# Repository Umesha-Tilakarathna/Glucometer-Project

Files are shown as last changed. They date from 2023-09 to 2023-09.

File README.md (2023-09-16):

# Glucometer Project
 
The project is a glucometer, that displays the glucose level of the body through
invasive means. When a glucose strip is inserted and a blood drop is placed, the
glucometer processes the reading to display the glucose level in mg/dL. The proportional
current signal generated in the strip is amplified, converted to voltage and processed
using the microcontroller and displayed finally.

The repository contains the Schematic Designs, Altium Designs, Solidwork Designs, 
and the code that was used to process the analog signal. 

gluco

strip

battery

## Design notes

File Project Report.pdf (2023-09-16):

## Department of Electronic & Telecommunication Engineering University of Moratuwa

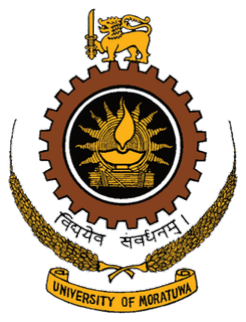
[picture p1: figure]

### EN 2160 - Electronic Design Realization

Final Project Report

### Glucometer

Submitted by:

Tilakarathna. U. A 200664P

## Contents

1 Introduction | 2
2 Product Specifications | 2
3 Functionality | 2
4 Product Architecture | 4
5 PCB Design | 5
6 Enclosure Design | 11
7 Instructions of Assembly | 13
8 Testing for functionality | 13
9 Areas of possible improvement | 13

## Abstract

The project is a glucometer, that displays the glucose level of the body through invasive means. When the glucose strip is inserted and a blood drop is placed, the glucometer processes the reading to display the glucose level in mg/dL. The proportional current signal generated in the strip is amplified, converted to voltage and processed using the microcontroller and displayed finally..

## 1 Introduction

Diabetes is a prevalent and serious disease affecting approximately 400 million people worldwide, and it ranks as the 8th leading cause of death. Managing diabetes is crucial for patients to maintain healthy blood glucose levels and prevent complications. At pharmacies, patients can find a wide variety of blood glucose meters along with their accompanying test strips.

The glucometer functions through the action of a disposable test strip that should be connected into the meter. By performing a finger prick to obtain a small droplet of blood, and loading the blood onto the test strip the blood glucose level is read.

## 2 Product Specifications

After connecting the glucose test strip to the device while the device is switched on, the button on the box should be pressed after placing blood on the strip. Then the glucose level can be observed after 5 seconds that is taken to the reading to achieve steady state. The reading is fed to the atmega328p microcontroller which is connected to an arduino nano board, for processing, and the final output is displayed on a 0.96” OLED display.

The power is supplied by two 2032 3.6V coin cell batteries to ensure the light weight and portability of the device. Three power regulators are used to obtain the required voltages to power the amplifiers, and also for the functionality of the test strip connector.

## 3 Functionality

The device contains a Onetouch Ultra test strip connector to connect the glucose strip to the device. This reading is achieved by amplifying the current generated by the glucose strip, which is proportional to the glucose level of the body by an enzymatic chemical reaction. This current is converted to a voltage by the opamp circuit and is input to the microcontroller as an analog input. Reference voltages of 2.4V and 2.1V is used in the amplification by connecting the voltages to the test strip electrodes through the opamp circuitry.

The reading is generated by the atmega328p microcontroller which is in the arduino nano board connected. The reading should be calibrated before use. For this, an existing glucometer and also a control solution which has a specified glucose level is required. Depending on the values the code should be changed. An OLED display of 0.96” inches is used to display the reading to the user. These are connected to the microcontroller using SDA and SCL pins. Also, the button that resets the reading is also connected to the microcontroller.

Further, an analog switch CD4066BM96 is connected to reset the circuitry.

LM317LCDR is used to generate the 2.1 V. The output voltage of this regulator is adjustable. Therefore, a 1k variable resistor was used for the adjustments. A TPS76925DBVT is used to generate the 2.5V output. To generate the 5V required for the opamps, a 7805 regulator was used.

### 3.1 Functionality of the test strips

There are three electrodes printed into the test strips: a reference electrode, a counter electrode and a working electrode. A fixed voltage is applied and the resulting current after the blood is loaded is monitored. The current response is then related to the glucose concentration through calibration.

Typically the electrodes are coated such that an enzymatic chemical reaction occurs at the electrode surface and this reaction dictates the resulting current. The glucometer developed uses Onetouch Ultra test strips. Here, the current after a fixed time, which is after a short initial transient is used for calibration.

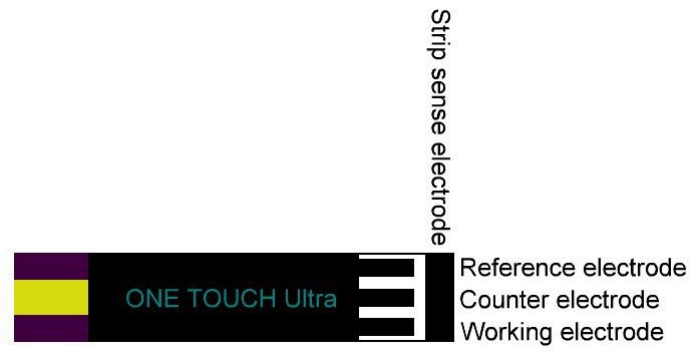
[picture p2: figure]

Figure 1: Onetouch Ultra Test Strip

## 4 Product Architecture

### 4.1 Block Diagram Abstraction of the Device

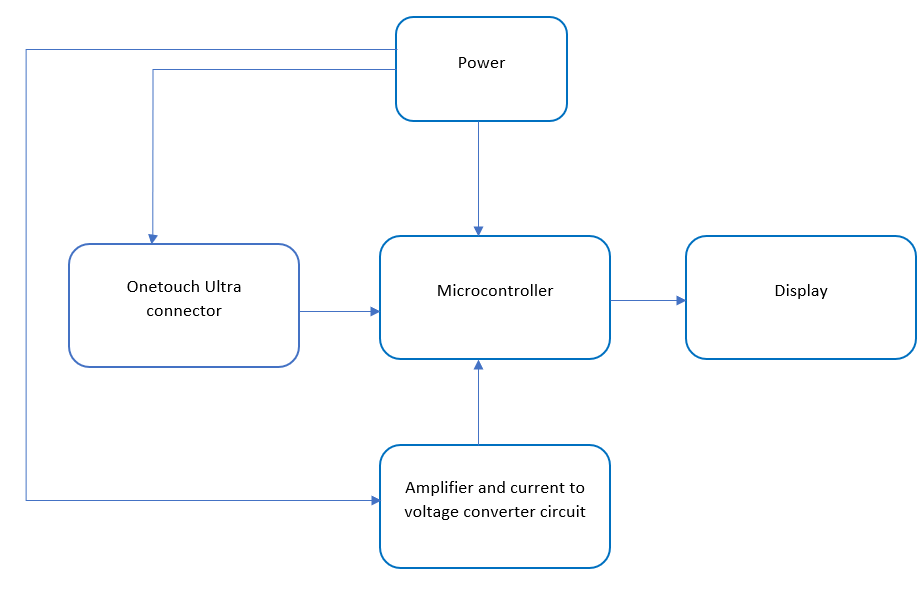
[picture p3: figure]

Figure 2: Block Diagram of the Device

## 5 PCB Design

### 5.1 Schematics

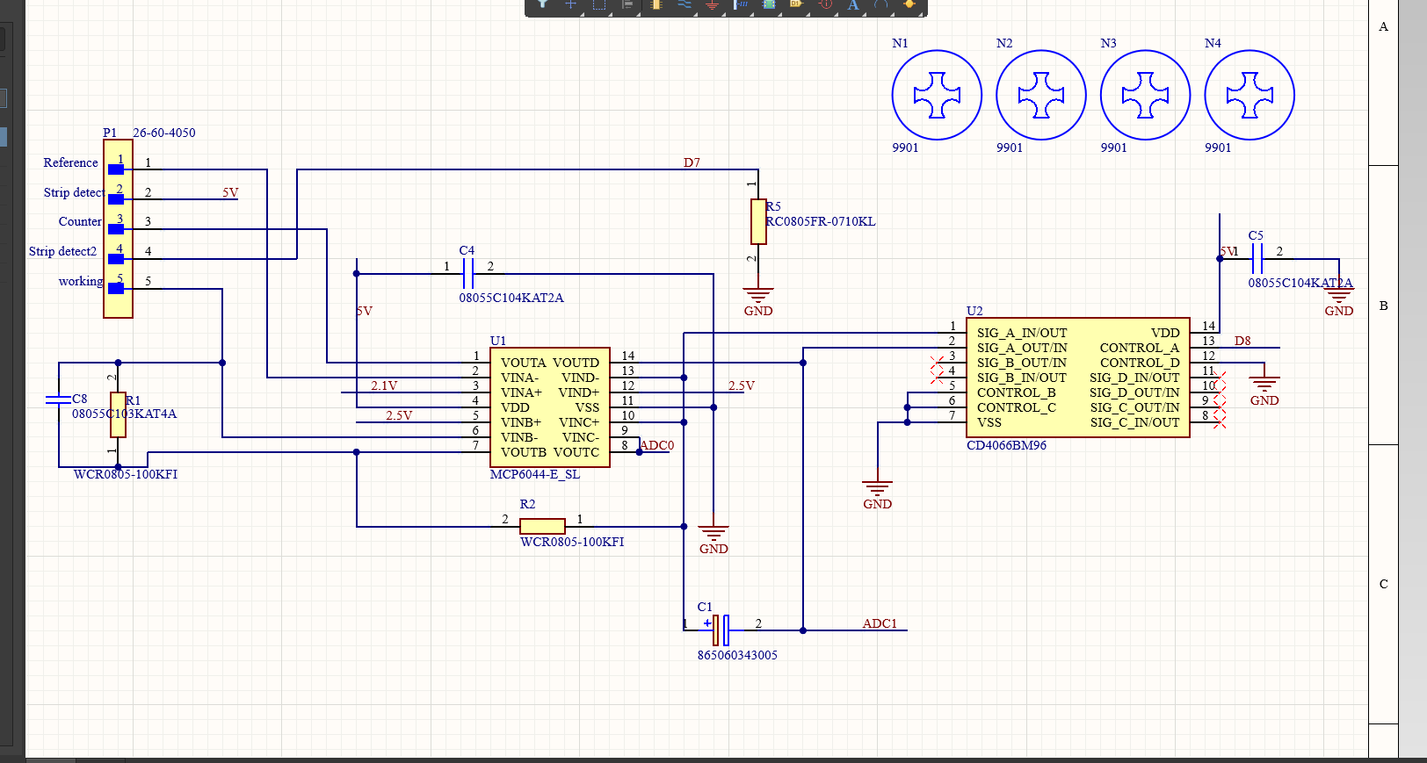
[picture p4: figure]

Figure 3: The Main Circuit

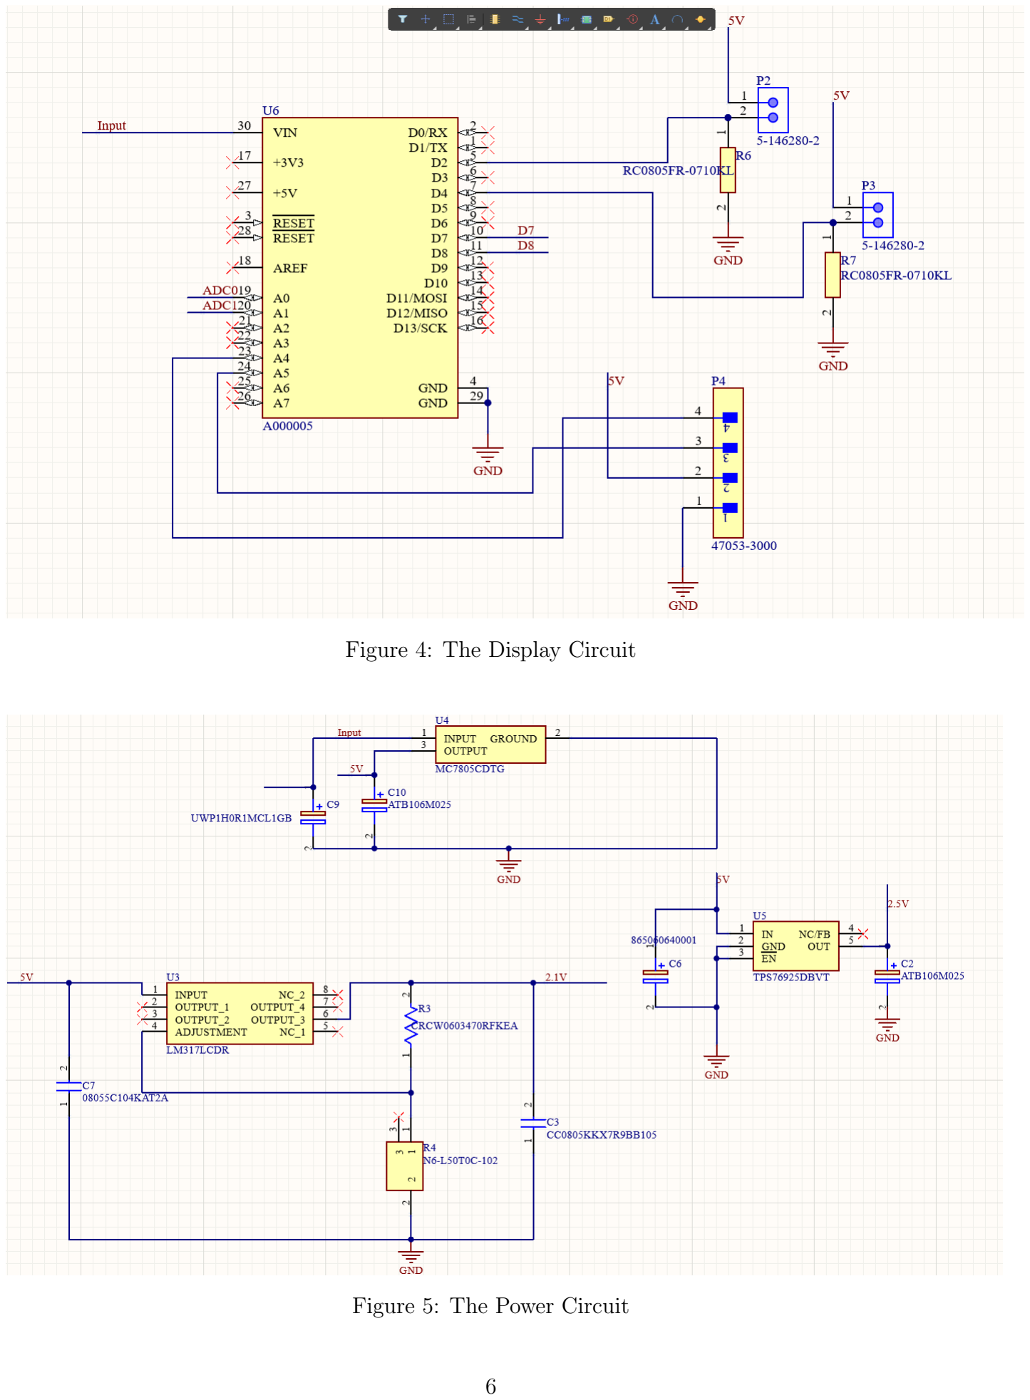
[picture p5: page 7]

Figure 4: The Display Circuit

Figure 5: The Power Circuit

### 5.2 Bill of Materials

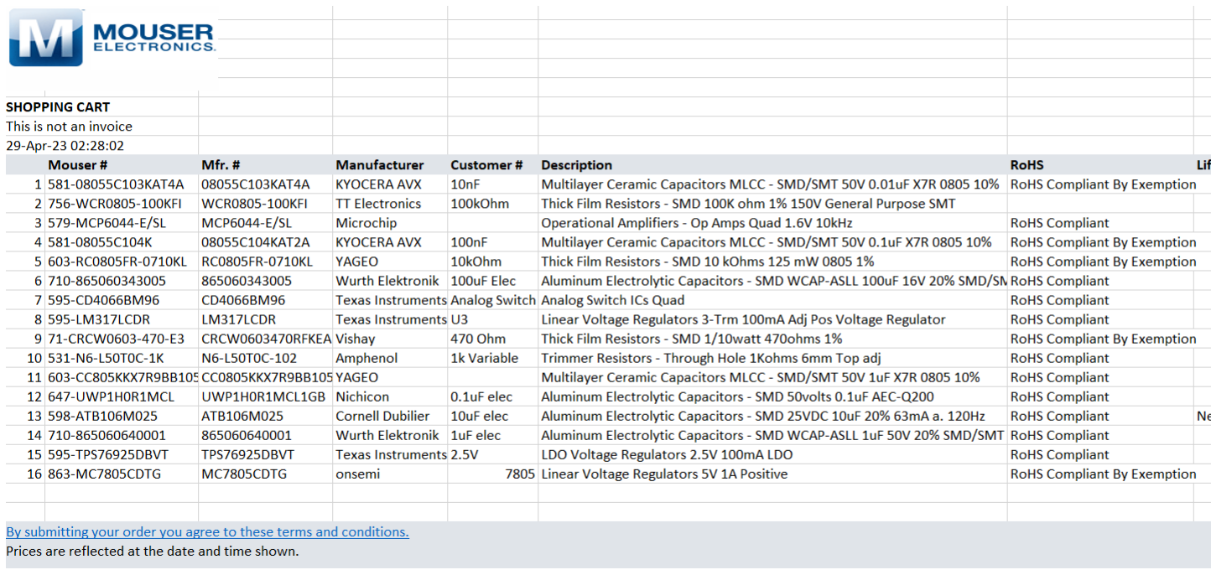
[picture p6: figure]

Figure 6: Bill of Materials of Components

Price of components | Rs. 8450
PCB printing | Rs. 2650
3D printing | Rs. 4000
Other | Rs. 2000
Total prototype production type | Rs. 17,100

### 5.3 PCB Design

The following images are of the PCB design.

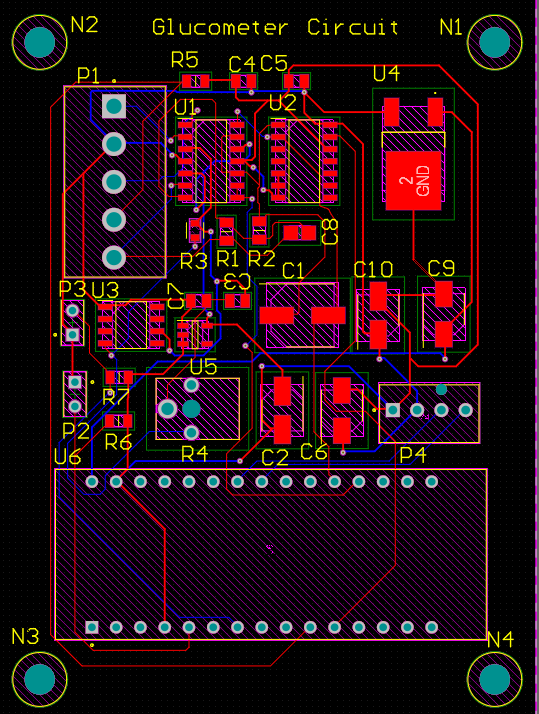
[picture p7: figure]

Figure 7: PCB Design

### 5.4 Programming the microcontroller

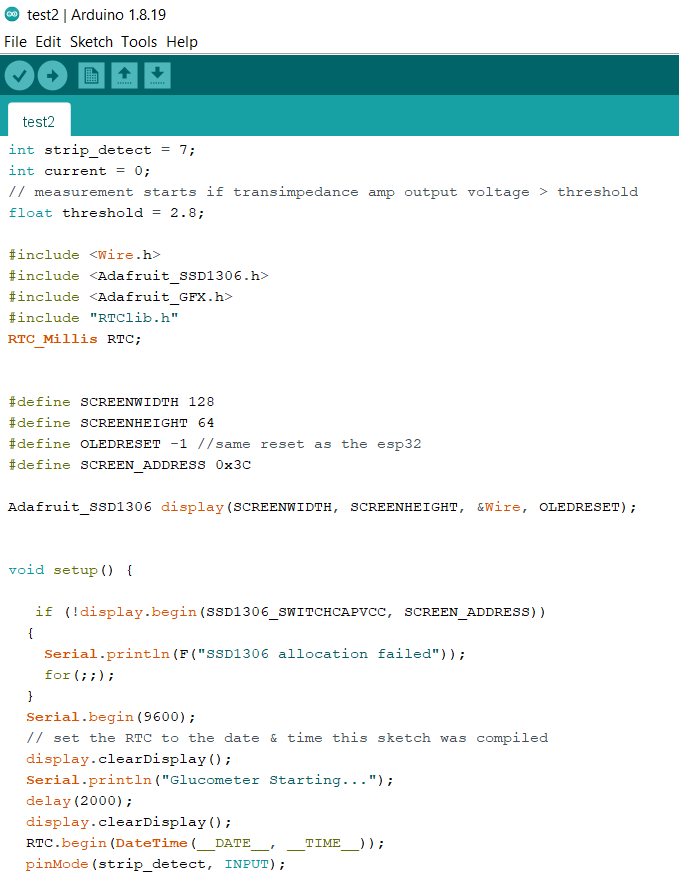
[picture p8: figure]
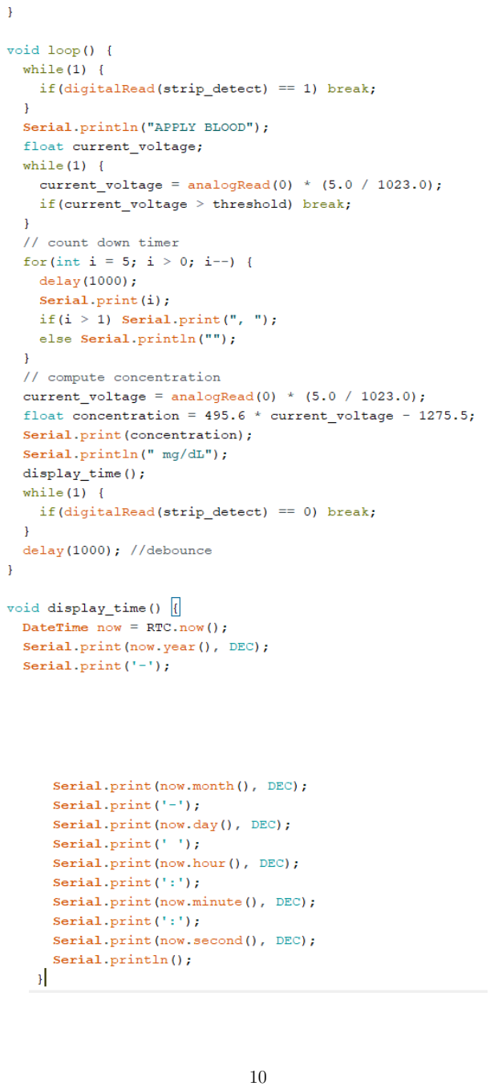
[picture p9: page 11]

## 6 Enclosure Design

The enclosure is made in such a way, that is portable and easy to use with minimal interactions with the device. The top part is connected with the display, and is made in such a way, that is removable for any repairs of the device. Also, the battery compartment can be open when needed.

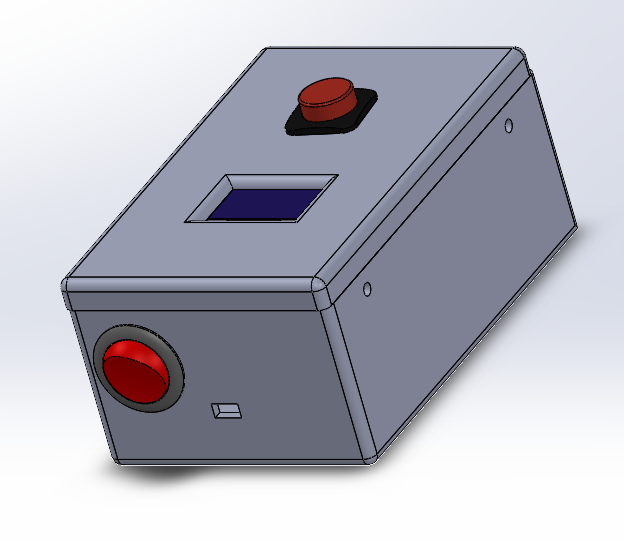
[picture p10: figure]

Figure 8: Top Appearance

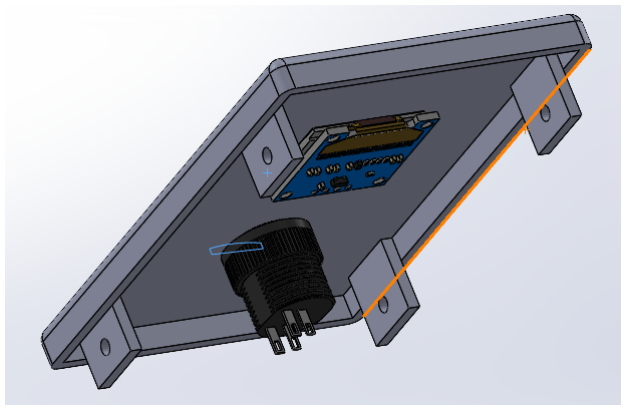
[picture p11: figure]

Figure 9: Top Lid Appearance

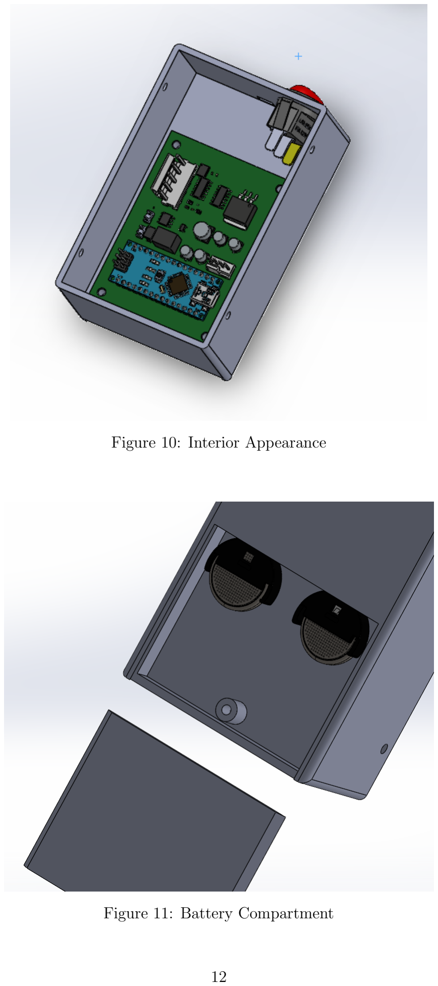
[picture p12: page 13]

Figure 10: Interior Appearance

Figure 11: Battery Compartment

## 7 Instructions of Assembly

The battery compartment wires should be connected to the switches of the top lid first. Then, the PCB can be fixed, thereafter the display can be connected to the top lid, and then to the PCB through the wires. Finally, the top and bottom parts of the enclosure are to be firmly closed using the screws. The battery compartment should also be closed using screws.

## 8 Testing for functionality

### 8.1 Power Verification

First, check if the input terminal receives power.
Then, 1. Check the output of the 7805 regulator. 2. Check the output of the LM317LCDR regulator, and adjust the output voltage to 2..1V using the R4, 1k variable resistor. 3. Check the output of the TPS76925DBVT and verify whether the output is 2.5V.

### 8.2 Calibration

This is a very important part of the glucometer production. In mass production, testing the value of a known control solution is done. But here, after checking the values of two control solutions from a working glucometer, the code should be changed after finding the necessary coefficients of the y=mx+c graph.

### 8.3 Code Verification

The code should start working only when the test strip is connected, and the micro-controller receives the connected signal. The glucose value should be displayed only when the button on the top lid is pressed. The displayed value shoould be checked through calibration procedure. In any further issue, the code should be verified with the simulation.

## 9 Areas of possible improvement

- The ergonomics can be improved to give a better user experience.
- A memory block can be used to store previous values for reference, or, the value can be transmitted to the phone via bluetooth to strore the value.

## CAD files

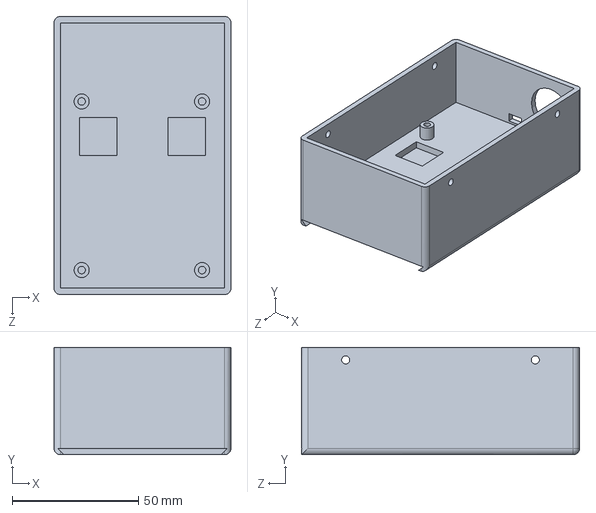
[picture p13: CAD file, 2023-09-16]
Solidworks/main.SLDPRT
70.0 x 42.5 x 110.0 mm

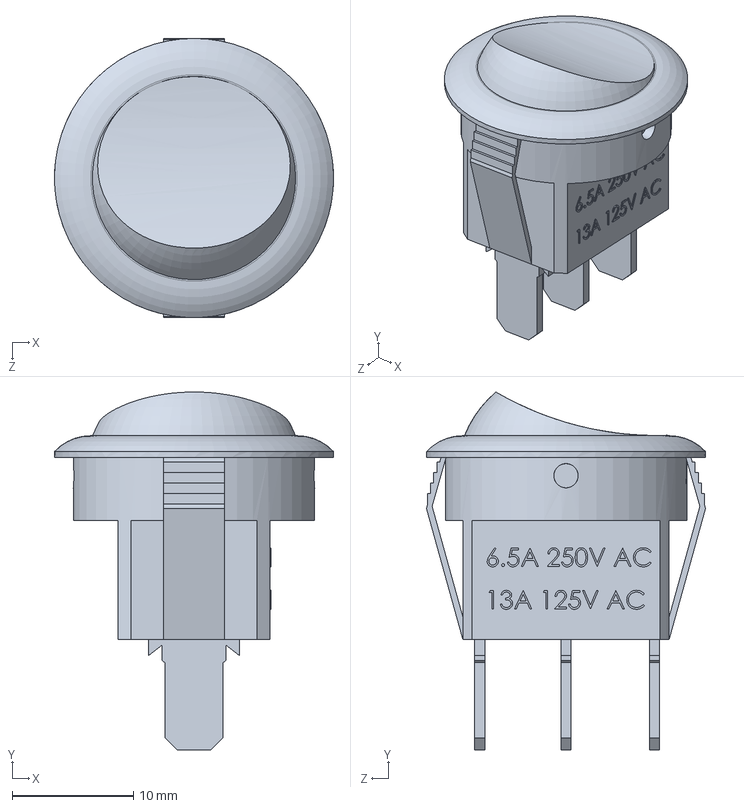
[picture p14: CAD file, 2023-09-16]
Solidworks/main switch.SLDPRT
23.0 x 29.5 x 23.0 mm

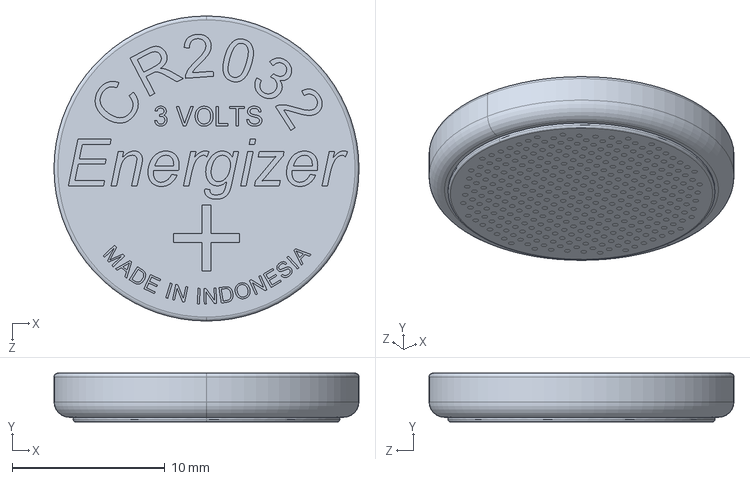
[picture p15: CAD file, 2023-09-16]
Solidworks/coin.SLDPRT
20.0 x 3.20 x 20.0 mm

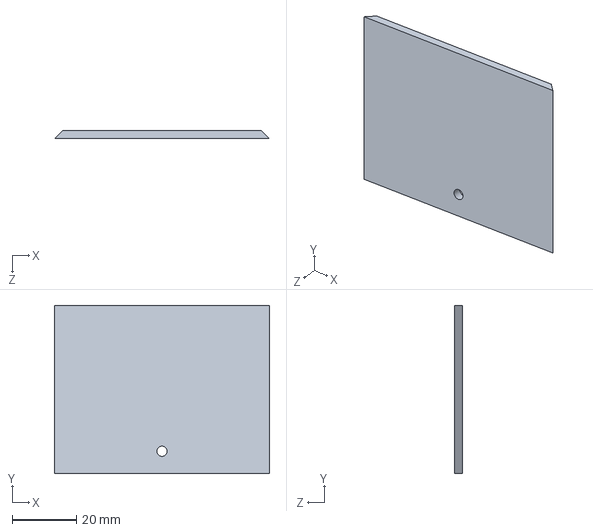
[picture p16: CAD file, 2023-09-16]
Solidworks/lid.SLDPRT
67.0 x 52.5 x 2.50 mm

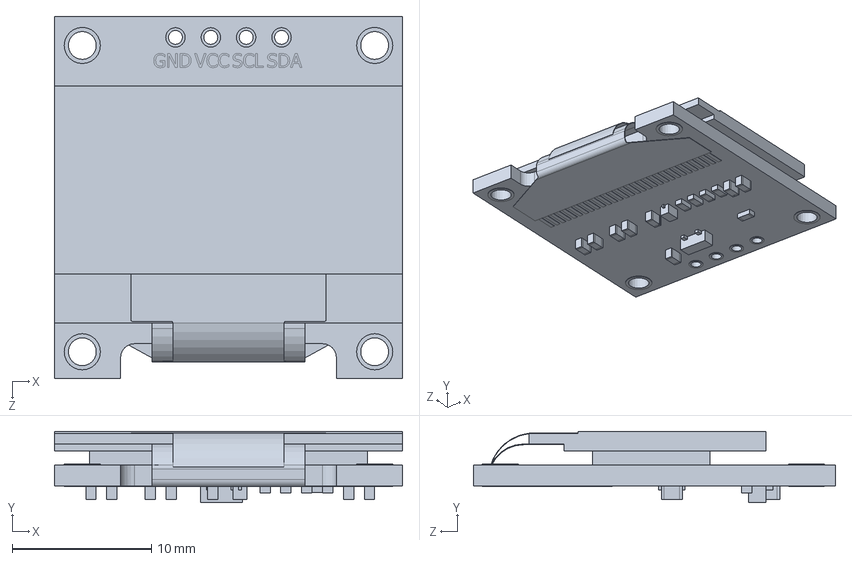
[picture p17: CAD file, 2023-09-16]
Solidworks/OSSD-128x64.SLDPRT
25.0 x 5.10 x 26.0 mm

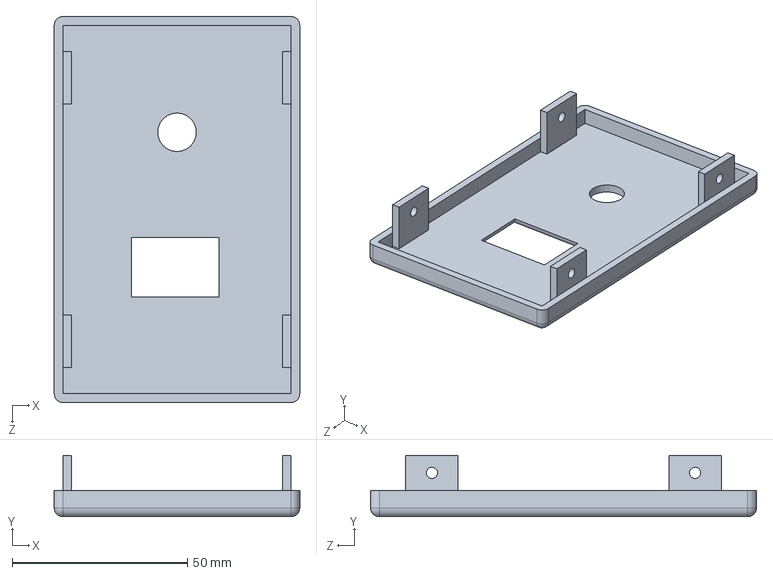
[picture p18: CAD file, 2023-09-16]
Solidworks/top lid.SLDPRT
70.0 x 17.5 x 110.0 mm

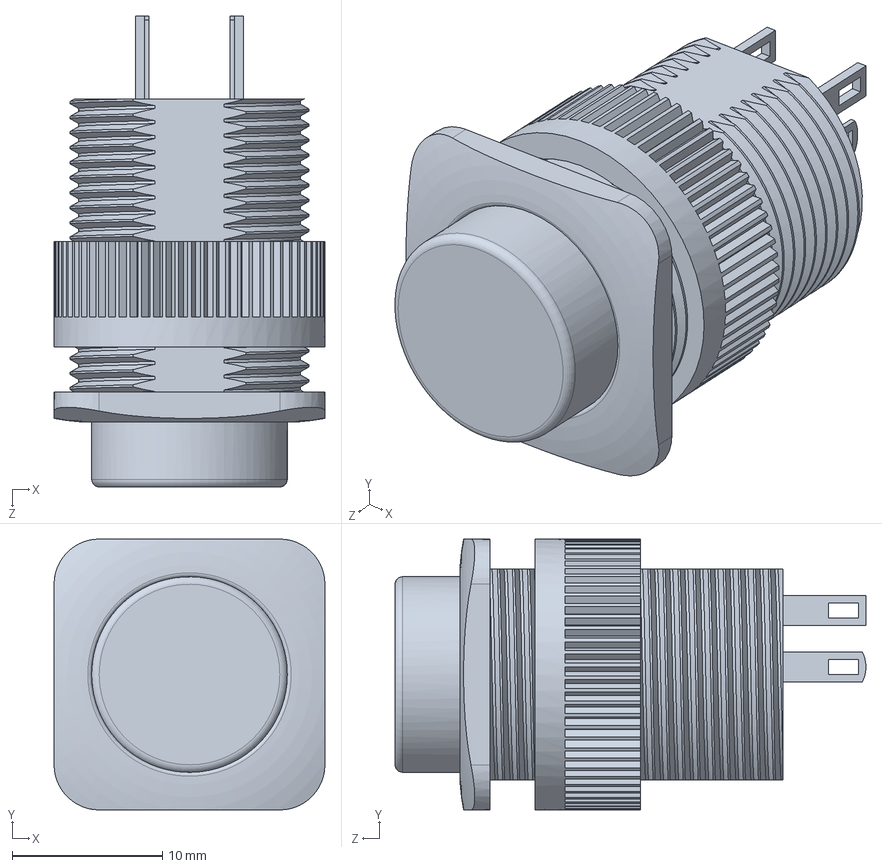
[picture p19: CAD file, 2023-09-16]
Solidworks/pushbutton.SLDPRT
18.0 x 18.0 x 31.3 mm

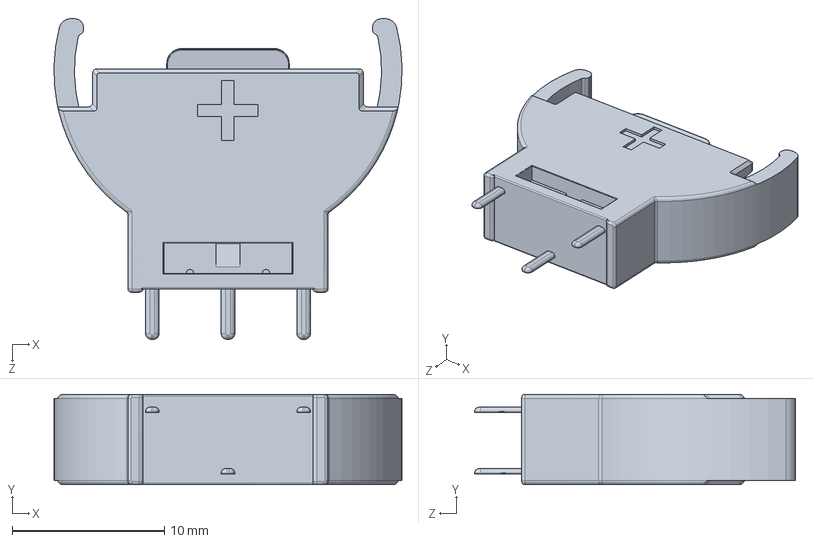
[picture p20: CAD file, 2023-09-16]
Solidworks/batteryholder.SLDPRT
22.9 x 5.95 x 21.1 mm
